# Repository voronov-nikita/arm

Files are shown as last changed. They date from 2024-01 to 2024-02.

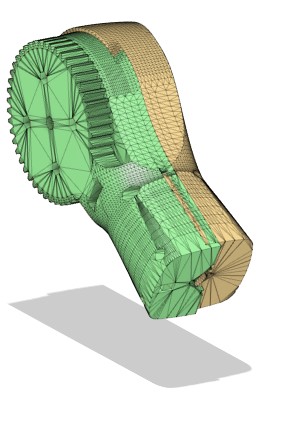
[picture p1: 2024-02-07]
scheme/5.jpg

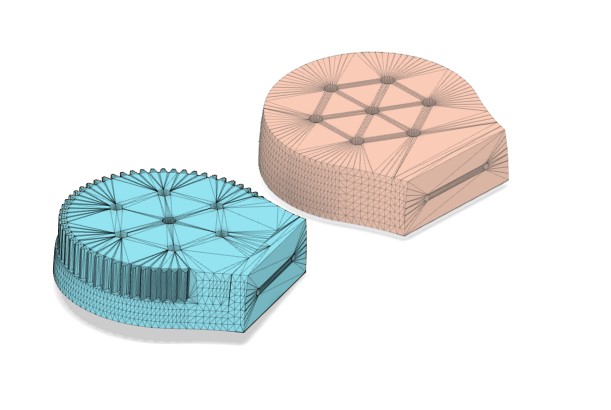
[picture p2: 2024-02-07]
scheme/4.jpg

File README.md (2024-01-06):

# ARM

<div align="center">
  Изображение
</div>

Проект - робот манипулятор на базе Arduino с особым управлением.

<br><br>

## Содержание

1. [О проекте](/README.md#о-проекте)
2. [О проекте](/README.md#используемые-компоненты)
3. [Структура проекта](/README.md#структура-проекта)
4. [Лицензии проекта](/README.md#лицензии)
5. [Полезные ссылки](/README.md#полезные-ссылки)

## О проекте

## Используемые компоненты

1. фывы
2. цацс
3. ывс
4. ысыв

## Структура проекта

## Лицензии

Проект распространяется с открытым исходным кодом под лицензией [MIT](/LICENSE).

## Полезные ссылки

1. [arduino.cc](https://www.arduino.cc)
2. [amperka.ru](https://amperka.ru/)

<br><br>

###### 06.01.2024

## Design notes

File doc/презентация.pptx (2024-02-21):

## Робот манипулятор

Государственное бюджетное общеобразовательное учреждение города Москвы «Школа № 1532»

11 класс, ГБОУ школа № 1532,
Воронов Никита Рустамович 11 «А»
Руководитель:
учитель информатики, ГБОУ школа №1532,
Кузьмин Михаил Игоревич

## Идея проекта

Создании универсальной и гибкой мехатронной системы, обеспечивающей автоматизированное выполнение разнообразных задач с высокой точностью и эффективностью.

## Принципы манипулятора 1 3 4 2

Механика

- Физическая структура манипулятора
- Кинематика и динамика движений

Восприятие

- Система сенсоров робота
- Обработка данных сенсоров для расчета положения

Управление

- Алгоритмы управления для точного перемещения
- Система обратной связи для коррекции движений

Взаимодействие

- Интеграция манипулятора с другими системами
- Возможность взаимодействия с внешней средой

## Этапы реализации

Подготовка материалов

- Создание 3Д моделей
- Выбор компонентов

Реализация материалов

- Печать готовых моделей
- Сборка устройств

Программирование

- Разработка специального скетча и прошивка обоих устройств

Тестирование

- Тестирование готового оборудования

## Распределение времени

Моделирование

Печать моделей на 3Д принтере

Программирование устройств

Тестирование

20%

50%

25%

5%

## Где можно применить?

## Способы применения

- Опасные для жизни места
- Труднодоступные места
- Технические производства
Все зависит от пользователя!

## Схема подключения перчатки

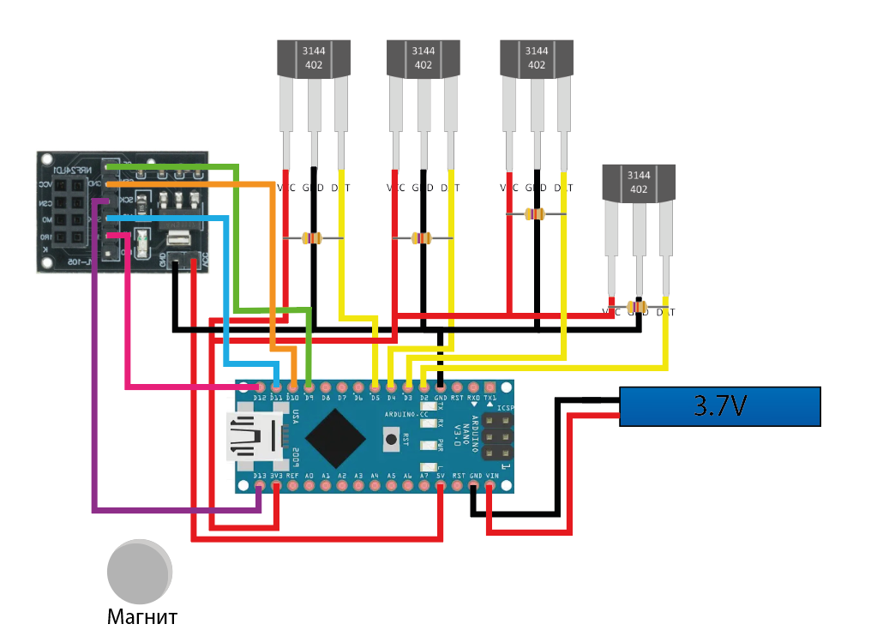
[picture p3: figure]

## Манипулятор

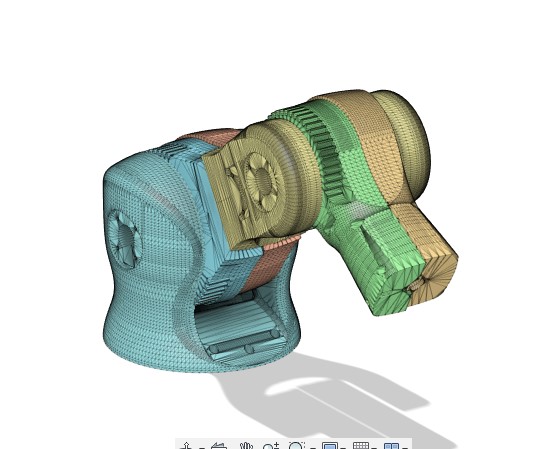
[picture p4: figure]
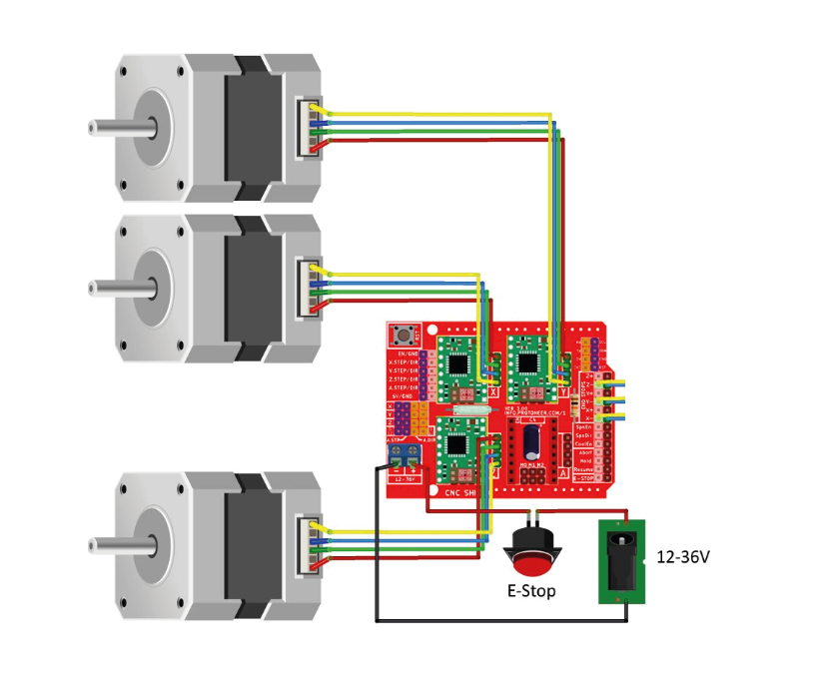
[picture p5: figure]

## Открытый исходный код

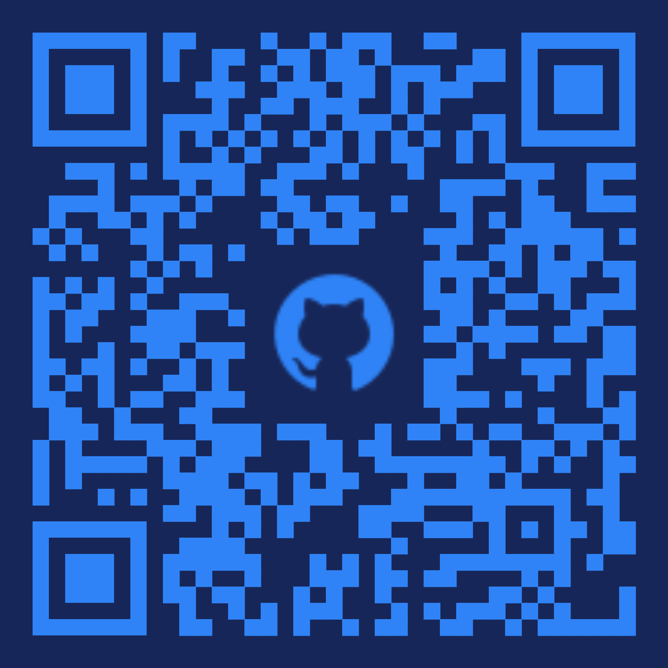
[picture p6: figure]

A

Код манипулятора

Исходный код манипулятора в виде arduino скетча

C

Модели

Исходные модели 3Д печати

B

Код перчатки

Исходный код перчатки в виде arduino скетча

D

Лицензия

Проект распространяется под лицензией MIT

## Спасибо

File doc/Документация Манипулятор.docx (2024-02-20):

Государственное бюджетное общеобразовательное учреждение города Москвы «Школа № 1532»

Разработка робота-манипулятора с копирующим управлением на основе жестов руки человека

11 класс, ГБОУ школа № 1532,

Воронов Никита Рустамович 11 «А»

Руководитель:

учитель информатики, ГБОУ школа №1532,

Кузьмин Михаил Игоревич

Москва, 2024

# Содержание

1. Поисково-исследовательский этап 3

1.1. Актуальность проекта 3

1.2 Цели и задачи 3

1.3 Анализ аналогов 4

1.4 Функциональная схема и формулировка технического задания 6

2. КОНСТРУКТОРСКО-ТЕХНОЛОГИЧЕСКИЙ ЭТАП 8

2.1 Выбор технического оборудования 8

2.2 Конструкционные особенности 9

3. Результаты 12

4. Приложение 13

4.1 Программный код 13

4. Список используемых ресурсов 13

# 1. Поисково-исследовательский этап

## 1.1. Актуальность проекта

На данный момент в мире активно развивается автоматизация производств и логистики с использованием различных видов роботов. Роботы-манипуляторы, управляемые инновационными методами, становятся важным направлением в робототехнике. Этот проект фокусируется на создании прототипа робота-манипулятора с управлением через контроллер-перчатку. Этот подход не только обеспечивает эффективное взаимодействие человека с роботом, но и решает проблемы эргономики и удобства управления.

Такой робот может быть применен в различных сферах, таких как медицина, строительство, промышленное производство, а также в ситуациях, где важны точность и чувствительность воздействия. Контроллер-перчатка делает управление роботом более естественным и интуитивным, уменьшая необходимость специализированного обучения пилотов устройства.

Проект также решает задачи, связанные с эргономикой и удобством управления. Это делает робота-манипулятора более доступным и простым в использовании, что может повысить эффективность в различных областях. Робот с контроллером-перчаткой особенно ценен в условиях, где требуется высокая точность и тонкость взаимодействия с объектами, в том числе в зонах, где человеку находиться даже короткий промежуток времени опасно.

Поэтому разработка технологически передового робота-манипулятора и инновационного метода управления, способствует улучшению взаимодействия человека с техникой в различных областях применения.

## 1.2 Цели и задачи

Цель работы: разработать полноценную модель робота манипулятора с управлением через специальный контроллер-перчатку.

Для успешного и эффективного выполнения цели проекта необходимо решить ряд следующих задач работы:

1. Проанализировать аналоги и готовые прототипы;

Провести исследование рынка и технологических решений для выявления существующих аналогов и прототипов, определить их преимущества и недостатки.

2. Составить функциональную схему продукта;

Определить основные функциональные элементы и взаимосвязи между ними, создавая понятную схему для последующего проектирования.

3. Составить электрическую схему модели;

Разработать детальную электрическую схему, описывающую подключение и взаимодействие электронных компонентов робота.

4. Разработать трехмерную модель конструкции в программе 3D моделирования;
5. Подобрать необходимые компоненты и материалы;
6. Разработать печатные/макетные платы для размещения электроники;

Создать дизайн печатных плат, обеспечивающих эффективное размещение и взаимодействие электронных элементов.

7. Изготовить/Подготовить материалы для реализации модели робота;
8. Собрать конструкцию робота и объединить все компоненты;

Выполнить сборку робота, установить компоненты согласно проектной документации, обеспечивая их взаимодействие.

9. Разработать программу для манипулятора и перчатки;
10. Запрограммировать перчатку и манипулятор;
11. Протестировать и модифицировать конструкцию и электронику робота;
12. Оценить и представить выполненную работу.

## 1.3 Анализ аналогов

В процессе исследования были рассмотрены аналоги и прототипы, представленные другими известными производителями роботов или командами энтузиастов. Подробная информация о сравнительных характеристиках этих манипуляторов приведена в таблице 1. В таблице представлена детализированная информация о ключевых особенностях и параметрах этих манипуляторов, призванных воплощать в себе передовые технологии и инженерное мастерство.

Таблица 1. Анализ аналогов роботов-манипуляторов, представленных на рынке.

Название | Визуальная картинка | Характеристики

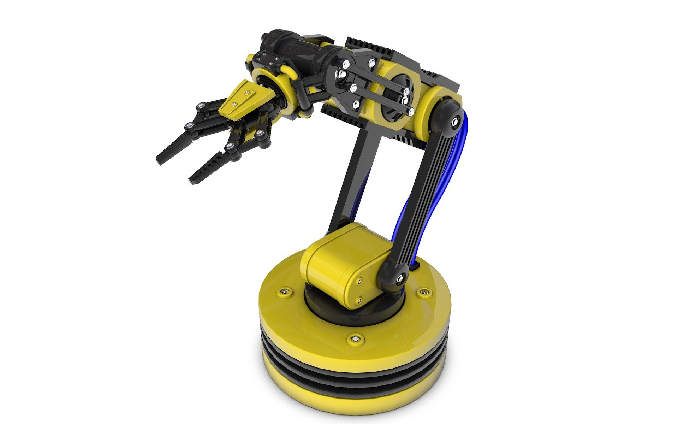
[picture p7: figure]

Робот-манипулятор LD-tg1400-6 | | Полезная нагрузка манипулятора достигает 6 кг. Рабочий радиус взаимодействия в районе 1000 мм Конструкция описана в виде Шарнирно-сочлененной структуре. Число степеней свободы - 4. Повторяемость: ±0.05 мм. Вес около 60 кг. Рабочая температура находиться в диапазоне -20°C~80°C

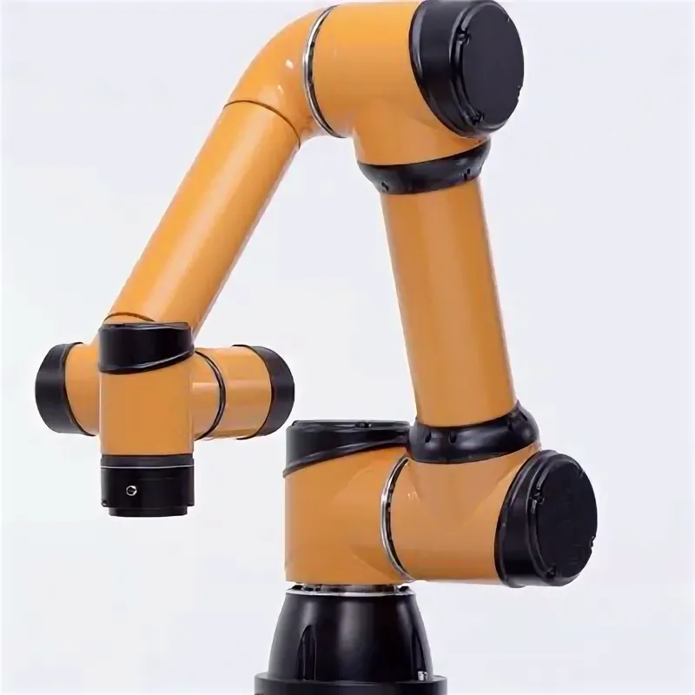
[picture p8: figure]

Манипулятор AUBO i5 | | Манипулятор AUBO i5 предполагает полезную нагрузку до 6 кг и рабочий радиус в 1000 мм. В его конструкции присутствует 6 степеней свободы, обеспечивая высокую гибкость. Повторяемость в пределах ±0.1 мм, вес составляет примерно 40 кг. Способен эффективно функционировать в широком температурном диапазоне от 10°C до 50°C

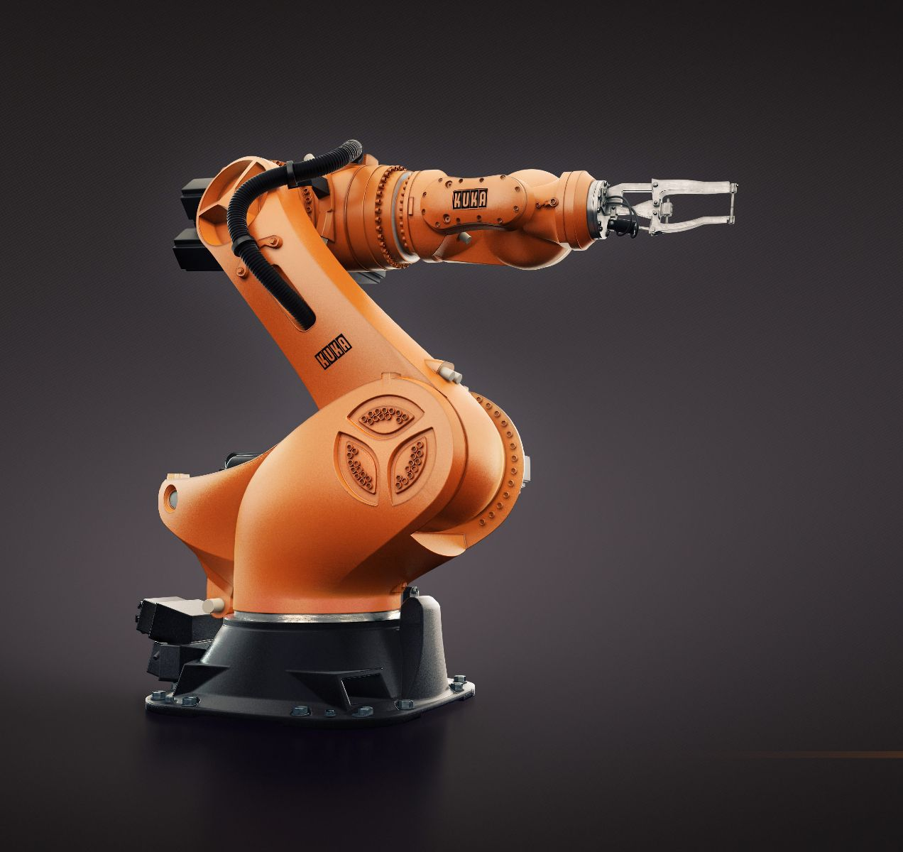
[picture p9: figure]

Робот-манипулятор Kuka KR AGILUS | | Полезная нагрузка: от 3 до 10 кг. Рабочий радиус - от 600 до 1100 мм. Основная структура робота: Шарнирно-сочлененная конструкция с 6 степенями свободы. Повторяемость: высокая точность с повторяемостью в пределах ±0.02 мм. Вес в диапазоне 51-70 кг. Рабочая температура: стандартно в диапазоне от 10°C до 55°C.

Все эти манипуляторы имеют идентичную структурную особенность - последовательную кинематику, однако их параметры значительно отличаются друг от друга.

## 1.4 Функциональная схема и формулировка технического задания

Основной функциональной особенностью данного манипулятора является возможность управления им с использованием специальной перчатки, оборудованной сенсорами и датчиками. Эти устройства на перчатке реагируют на движения рук и пальцев пользователя, а затем транслируют эти данные в манипулятор для выполнения соответствующих задач. Для тех, кому вариант с управлением через перчатку не подходит, можно использовать другой контроллер, напоминающий обычный джойстик со стандартным управлением.

Перчатка обеспечивает точное и мгновенное распознавание жестов и движений, что позволяет оператору контролировать манипулятор с высокой степенью прецизионности. Такое управление особенно полезно в задачах, где требуется тонкая настройка и точность, например, в хирургии, производстве микроэлектроники или при работе с труднодоступными объектами.

Кроме того, система может быть дополнена силомоментной обратной связью, позволяющей пользователю чувствовать вес, форму и текстуру объектов, с которыми взаимодействует манипулятор. Это создает ощущение присутствия и повышает уровень контроля оператора.

Такой манипулятор с копирующим управлением представляет собой интегрированную и эргономичную систему, которая может быть применена в различных областях, требующих высокой точности и удобства управления.

В итоге было сформулировано следующее техническое задания:

1. Необходимо обеспечить стабильную связь между роботом манипулятором и контроллером удаленного управления. Перчатка или иной контроллер требуют постоянного питания, так как канал связи должен быть постоянно занят. Реализовать постоянную обратную связь между манипулятором и контроллером не сложно, однако хочется, чтобы при работе от аккумулятора перчатка или контроллер не разряжались в один момент, даже если данных не поступало.
2. Необходимо реализовать алгоритмы калибровки шаговых двигателей. Вся проблема в том, что при использовании шаговых двигателей в момент запуска, в большинстве случаев, они берут за свою стандартную позицию ту, с которой запустилась, а не ту, которую подразумевается. Для исправления этого недочета есть несколько способов решения, одним из них является способ калибровки манипулятора с помощью специальных алгоритмов.
3. Реализовать схему считывания данных от пользователя и перевод их на манипулятор. Для этого необходимо использовать модель радиосвязи NRF. Данные с перчатки передаются на манипулятор по специальному радиоканалу, настроенного вручную.
4. Реализовать модель перчатки. В перчатке должен присутствовать микроконтроллер на базе Arduino. Данные об отклонении руки на заданном промежутке считываются с помощью датчика гироскопа-акселерометра mpu6050. В схеме должны присутствовать датчики магнитного поля или датчики холла. Закрепить датчики следует на 4-х пальцах перчатки, а на большом пальце той же перчатки необходимо разместить небольшой магнит.
5. Разработать алгоритм перевода угла наклона в скорость вращения определенного шагового двигателя. Для перевода угла наклона в скорость, вам необходимо учитывать изменение угла по времени. В физике и математике угловая скорость (или скорость вращения) обозначается символом ω (омега) и измеряется в радианах в секунду (рад/с).
6. Составить схему для манипулятора и реализовать ее в реальной жизни. Схема и 3Д модель должны соответствовать требованиям документации и правилам, описанным ГОСТ.
7. Разработать прошивку для перчатки и робота-манипулятора. Для реализации следует использовать микроконтроллер Arduino и среду программирования Arduino IDE. Необходимо, чтобы перчатка имела у себя 4 отдельных датчика холла на каждом пальце, за исключением большого пальца руки.
8. Протестировать систему в реальных условиях. Попробовать поднять предметы разной формы и веса в пределах допустимой нагрузки. В зависимости от проведенных тестов сделать техническую документацию, описывающие характеристики манипулятора.
9. Составить полную документацию к проекту.

# 2. Конструкторско-технологический этап

## 2.1 Выбор технического оборудования

Для проектирования моделей использовался Autodesk Fusion 360. Он является мощным программным обеспечением для компьютерного-помощи-в-проектировании (САПР), предоставляющим ряд преимуществ, объясняющих его широкую популярность. Интегрированный подход Fusion 360 предоставляет интегрированную среду для 3D-моделирования, инженерного проектирования, симуляции, CAM (компьютерно-чертежное проектирование) и облачного хранения. Это позволяет пользователям работать над всеми аспектами проекта в одной среде, что способствует синхронизации данных и упрощает взаимодействие между различными этапами проектирования. Широкий функционал Fusion 360 включает в себя множество инструментов для создания 3D-моделей, выполнения анализа напряжений и тепловых карт, создания инструментальных траекторий для станков с ЧПУ и многое другое.

Для программирования основного микроконтроллера ATmega2560 было решено использовать среду Arduino IDE с оболочкой под ATmega2560 и язык программирования C++. Этот микроконтроллер является основой Arduino Mega, что обеспечивает широкие возможности для разработки и управления различными периферийными устройствами. Необходимый чип как раз используется платой Arduino Mega, именно она в проекте и была взята.

## 2.2 Конструкционные особенности

Для дальнейшей работы определим необходимые компоненты копирующего управления. Начнем непосредственную разработку с выполнения схемы перчатки. В качестве датчиков, управляющих движениями робота-манипулятора было принято решение использовать датчик гироскоп-акселерометра mpu6050. В зависимости от угла отклонения и вычислительного ускорения формируется понятие того, куда, как и с какой скоростью должен вращаться определенный двигатель. Для обеспечения взаимодействия пользователя и манипулятора, а также для интерпретации показаний датчиков использована плата Arduino Nano. Связь между элементами осуществляется по радиоканалу, который обеспечивают модули NRF24, установленные как на перчатку, так и на сам манипулятор. В качестве питающего элемента использован аккумулятор типа 18650 на 3.7 В. Данного аккумулятора хватит для использования перчатки в автономном режиме без дополнительных модулей усиления. Таким образом схема сборки электронных компонентов приведена на рисунке 1.


Рисунок 1. Схема сборки устройства, считывающего жесты, закрепленного на перчатке.

Далее перейдем к разработке манипулятора. Для первого прототипа будем использовать шаговые двигатели типа NEMA17. Такие двигатели широко распространены на рынке и обеспечивают необходимую точность перемещений робота, однако они имеют небольшой момент силы. Чтобы нивелировать этот недостаток, в манипуляторе применяются зубчатые передачи, установленные на звеньях. Модель манипулятора, построенного в программе Fusion 360 приведена на рисунке 2.


Рисунок 2. Манипулятор, построенный в программе Fusion 360.

Производство будет выполнено на 3D-принтере Flying Bear 5, что обеспечит необходимое качество производимых деталей. На рисунке отмечено цветами разделение частей деталей для производства. Далее перейдем к формированию электронной схемы компонентов манипулятора.

Как было описано выше, для обеспечения перемещений роботом будут использованы двигатели типа NEMA17,которые будут подключены к плате Arduino с помощью драйвера A4988. Данный драйвер не требователен к управляющему сигналу, что делает его наиболее эффективным в этом проекте. Данные для перемещения Arduino будет получать с помощью радиомодуля NRF24. Сигнал можно усилить, поставив на место обычной NRF24 ту же модель, но с модулем усиления и антенной. Электросхема манипулятора приведена на рисунке 3.


Рисунок 3. Электросхема управления манипулятором.

Таким образом схема управления манипулятором составлена. Теперь необходимо обеспечить сборку и взаимодействие оператора с манипулятором. Для этого составлена программа на языке Arduino, приведенная в приложении.

# 3. Написание программного кода проекта

## 3.1 Программный код перчатки

Программный код перчатки реализован на языке программирования C++. Используемые библиотеки находящиеся в открытом доступе. На рисунке 4 представлен фрагмент кода, на котором происходит момент инициализации перчатки, открытие радиоканала и инициализация самой mpu6050. Уникальный адрес для радиоканала задается вручную, что может показаться не совсем эффективным, но надежным и постоянным. Это делает перчатку менее зависимой от конкретного разработчика или администратора.

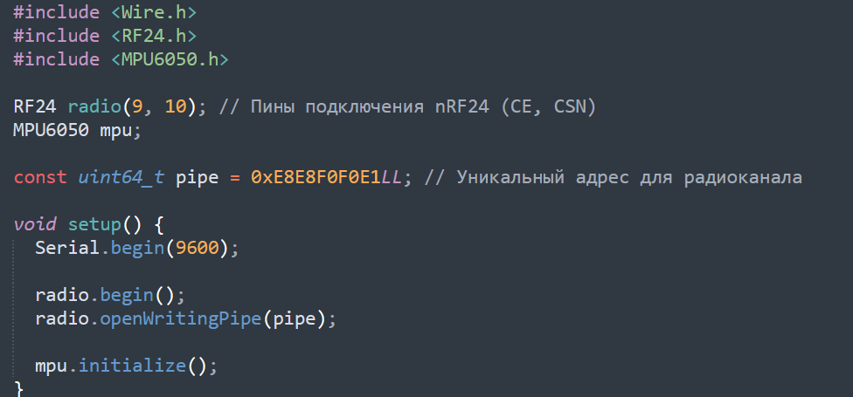
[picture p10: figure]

Рисунок 4. Пример программного кода для инициализации перчатки.

## 3.2 Написание программного кода манипулятора.

На рисунке 5 представлен код обработки полученных данных на стороне манипулятора.

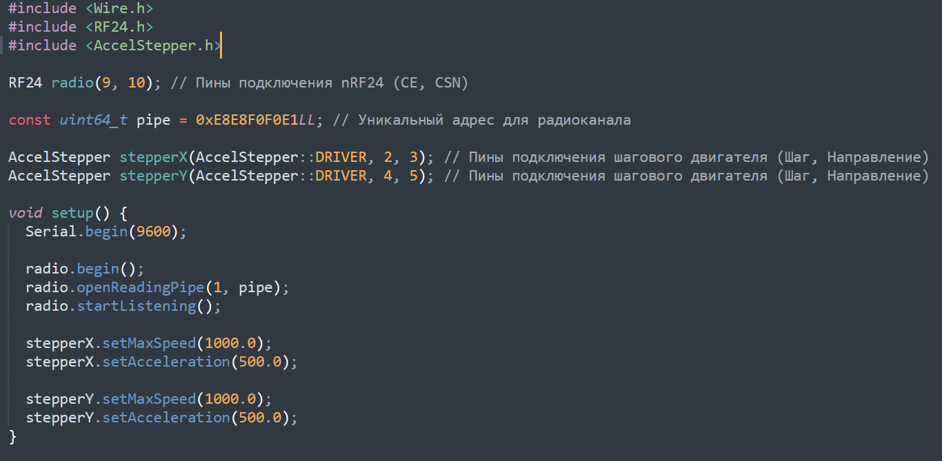
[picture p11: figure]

Рисунок 5. Пример обработки данных от перчатки.

Важно понимать, что номера радиоканалов должны совпадать друг с другом, иначе соединения двух модулей между собой не произойдет.

# 4. Результаты

Цели и задачи данного проекта выполнены в полном объеме. Разработана вся необходимая документация, построены модели и электросхемы, детали переданы в производство, где успешно выполнены. Произведена дополнительная механическая обработка деталей из-за некоторых незначительных дефектов производства. Схемы собраны и дополнительно скорректированы для документации. Написан программный код, и обеспечивается устойчивое соединение между оператором и манипулятором. Проект проходит стадии финальной отладки и оптимизации.

# 5. Список используемой литературы

1. Банци М.« Arduino для начинающих волшебников»

https://www.elec.ru/library/nauchnaya-i-tehnicheskaya-literatura/banci-arduino/ Дата обращения: 25.12.2023;

2. Олег Миловзоров, Иван Панков - «Электроника. Базовый курс»

https://krasnograd2008.ucoz.ru/load/uchebniki_dlja_vuzov/uchebniki_dlja_vuzov/oleg_milovzorov_ivan_pankov_ehlektronika_bazovyj_kurs/60-1-0-1887 Дата обращения: 16.01.2024;

3. «Основы 3д моделирования в Компас 3Д» https://youtube.com/playlist?list=PLivkchQQojUVkmjov0UZrLz2X70HkV4gK&si=_3Ym10-ELJgqKk2p Дата обращения: 3.02.2024;
4. Пол Шерц и Симон Монк «Практическая электроника для изобретателей»

https://zametkioknigah.blogspot.com/2015/02/practical-electronics-for-inventors.html Дата обращения: 8.01.2024;

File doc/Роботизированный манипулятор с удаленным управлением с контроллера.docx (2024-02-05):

Роботизированный манипулятор с удаленным управлением с контроллера

Работа ученика школы №1532:

Воронова Никиты Рустамовича

Руководитель проекта:

Кузьмин Михаил Игоревич

Введение

В основе разработки роботизированных устройств всегда лежит один принцип – облегчить какую-то рутинную задачу. Ярким примером этого принципа являются умные пылесосы. Они созданы с целью автоматизации и упрощения процесса уборки в доме. Эти роботы способны самостоятельно перемещаться по помещению, обнаруживать загрязнения и эффективно очищать поверхности. Такие устройства значительно снижают необходимость ручной уборки, освобождая время для более важных и интересных занятий.

Но мой проект не о роботе пылесосе. Есть вещи, которые людям сложно выполнять в каких-то местах. Обычно для таких целей создают роботов, которые могли бы в этом помочь. Роботизированный манипулятор – это один из таких роботов.

Суть манипулятора в том, чтобы в зависимости от общего положения всех своих двигателей выдавать определенную форму или позу, из которой в последствии можно выбрать необходимые действия.

О проекте

Проект разработан с целью обеспечить безопасное взаимодействие человека с разными объектами и в разных опасных ситуациях. Людям постоянно приходиться работать в сложных и опасных для жизни местах. Робот-манипулятор способен справиться с этой проблемой, предоставляя уникальные возможности для выполнения различных задач в опасных средах. Например, в ядерных электростанциях, где существует потенциальная угроза радиации, робот-манипулятор может осуществлять рутинные проверки, обслуживание и даже ремонт оборудования без участия человека.

В случае чрезвычайных ситуаций, таких как природные катастрофы или аварии на промышленных объектах, робот-манипулятор может быстро развернуться для поиска и спасения, а также для предотвращения дополнительных угроз. Его способность работать в сложных территориальных условиях и выполнять множество задач позволяет оптимизировать эффективность оперативных мероприятий.

В промышленности роботы-манипуляторы обеспечивают безопасность работников при обработке опасных материалов и в труднодоступных местах, где могут быть высокие температуры, ядовитые вещества или другие опасности. Это повышает производительность и снижает риск профессиональных заболеваний.

Также в медицинской сфере робот-манипулятор становится незаменимым помощником в хирургии, позволяя врачам проводить сложные операции с высокой точностью, минимизируя риски для пациента.

Манипулятор по своему строению похож на человеческую руку, с некоторыми модификациями. Подобно тому, как человек управляет своей рукой можно добиться того, как человек управляет роботом.

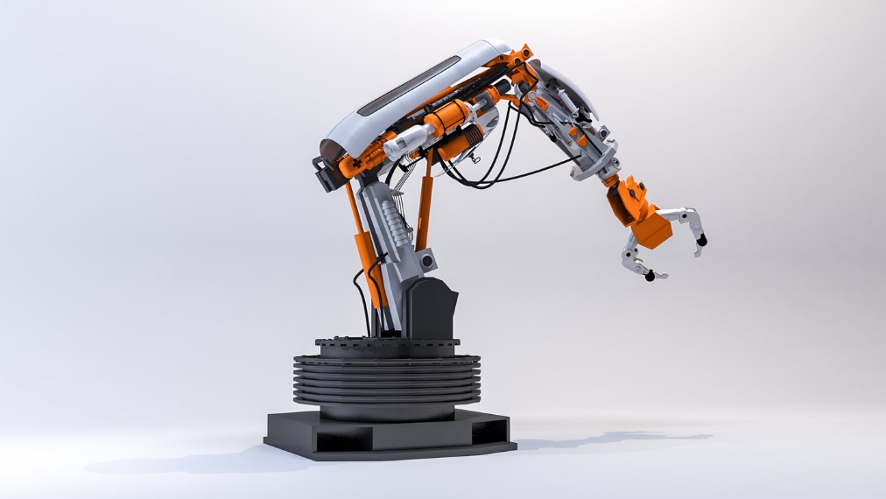
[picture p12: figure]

Рис.1 Пример робота-манипулятора

Вся система состоит из двух частей: роботизированный манипулятор и удалённый контроллер управления. Обмен данными происходит по радиоканалу с использованием модулей NRF24L01. Канал достаточно настроить один раз на обоих устройствах. Конечно, куда проще было бы настроить автоматический поиск свободных радиоканалов, но в таком случае есть рис попасть в чужой радиоканал, который находился в режиме ожидания. Таким образом возрастают риски того, что управление манипулятором может быть опасным или бессмысленным.

В основе идеи лежит сделать подобие роботизированного помощника, подобно тому, которого нам показали в фильме «Железный человек»

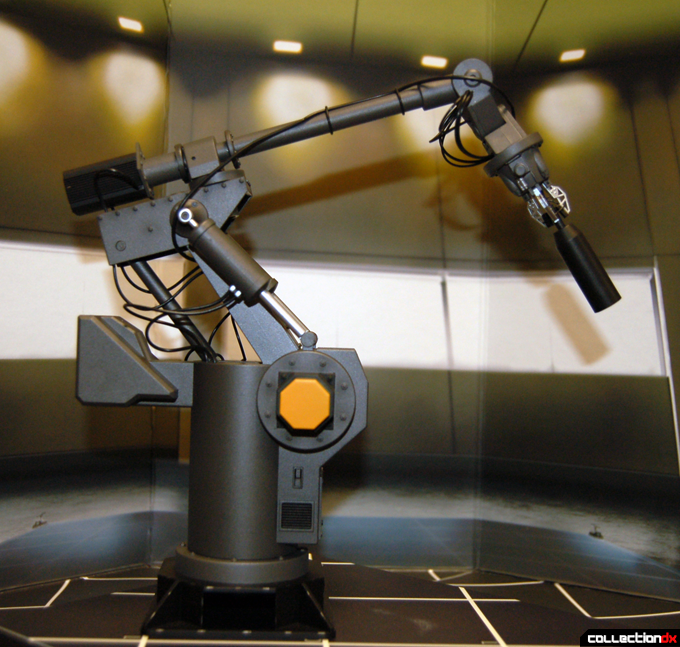
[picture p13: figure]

Рис.2 Пример манипулятора из фильма

Разумеется, что повторить все функции робота из фильма не получиться, но сама идея вполне реализуема.

Подробнее с файлами работы, готовым кодом и примерами использования можно ознакомиться по ссылке на репозиторий GitHub:

https://github.com/voronov-nikita/arm

Принцип работы

Как уже было сказано ранее, вся система состоит из ручного контроллера – перчатки и самого роботизированного манипулятора. Обе части работают на базе микроконтроллеров Arduino с различными усилителями. Рассмотрим принцип работы каждого из них по отдельности.

Перчатка – это специальный контроллер, который собирает данные о положении руки человека и отправляет соответствующие данные по радиоканалу. Данные, которыми обмениваются контроллер и манипулятор – это 3 угла отклонения (roll, pitch, throttle), 4 показателя от датчиков холла, положение перчатки по вертикальной оси и положение перчатки по оси вращения yaw. NRF модули свободно способны обмениваться большими данными в формате массивов. Таком образом для массива достаточно использовать только целые числа, не выходящие за пределы 16 битного представления числа. Следовательно, по формуле поиска общего объёма информации:

I=k*i

Можно получить такие параметры, где k – это количество информации, а i – размер каждого элемента этой информации. В нашем случае k – это размер массива, а i – это размер целых чисел в языке программирования C++, соответственно от 16 до 128 бит информации. Как раз размер массива умещает в себя 9 значений, необходимых для изменения движения манипулятора. А размер каждого должен умещаться в 16-битную разрядность двоичной системы счисления. Соответственно общий объем информации это 16бит * 9 = 144 бита. Скорость передачи данных у NRF24L01 в районе 0,25Мбайт/секунду. Переводя в обратные единицы, получим, что наш пакет данных дойдет и вернется за ~0,41 секунд. Разумеется, что это скорость при идеальных условиях, а в нашем мире легко получить помехи в соединении. Поэтому, с условиями погрешности, была взята скорость в диапазоне от 0 до 1 секунды. Этого всего уже достаточно, чтобы обеспечить практически бесперебойную связь на расстоянии до 2-х километров.

Для получения положения руки управляющего используется модуль гироскоп-акселерометра MPU6050 с Arduino совместимым стабилизатором.

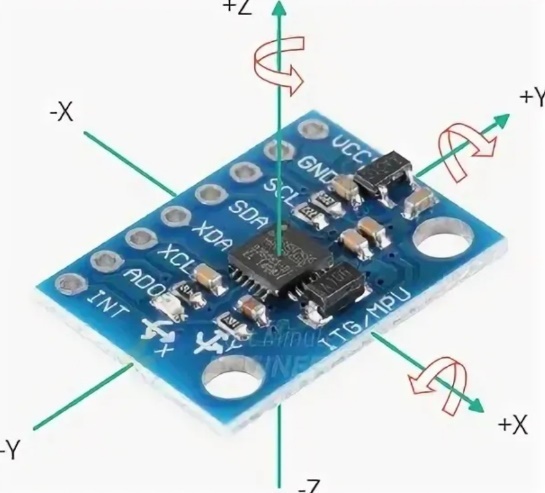
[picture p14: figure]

Для симметричных тел, вращающихся вокруг главной оси, момент импульса (L) равен произведению момента инерции тела (I0) на его угловую скорость вращения (ω0). Это выражается уравнением:

Рис.3 mpu6050

L=I_0 *w_0

Момент инерции (I) зависит от массы и распределения массы относительно оси вращения. Вектор момента импульса (L) определяет точность работы гироскопических приборов: чем он больше, тем устойчивее и точнее функционируют эти приборы. Но при таком раскладе мало просто использовать некоторые значения, вычисляемые из этой формулы, нам необходимо сделать что-то вроде преобразователя. Используя данные гироскопа для оценки угла, легко можно найти угол отклонения (θ), интегрируя угловую скорость (ω):

θ(t)=θ_0 +∫_(t_0)^t ω( ʇ)Δ ʇ

Однако, данная формула подвержена ошибкам из-за дрейфа гироскопа, и поэтому для более точных результатов часто применяют фильтры, такие как фильтр Калмана, для коррекции данных.

Фильтр Кальмана начинает с предсказания текущего состояния системы, основываясь на предыдущих измерениях и знании о том, как система обычно изменяется. Например, если мы измеряем угловую скорость (как быстро что-то вращается), мы можем предсказать, на сколько изменится угол поворота за следующий короткий период времени. Затем фильтр Кальмана принимает новое измерение текущего состояния системы. Но измерения часто содержат шумы или ошибки. Фильтр сравнивает предсказание с фактическим измерением и определяет, насколько они различаются. Затем фильтр учитывает, насколько ему можно доверять предсказанию и насколько измерение подвержено шумам. На основе этих сравнений фильтр корректирует предсказание, чтобы получить более точное состояние системы. Важно отметить, что фильтр Кальмана учитывает как измерения, так и динамические свойства системы. Он стремится минимизировать ошибки оценки состояния, учитывая неопределенность в данных и модели системы. Это позволяет ему быть эффективным инструментом для оценки состояния в реальном времени в различных областях, таких как навигация, управление роботами и другие приложения.

Для отслеживания режимов работы и изменении каких-то прочих параметров используются цифровые датчики холла, расположенные в районе 4-х пальцев. Всего из 4-х датчиков формируются специальные команды для перчатки. Для активации датчика необходимо поднести выбранный датчик к большому пальцу руки, именно там располагается магнит для активации датчика. К примеру, если замкнуть перчатку на указательный и большой палец, то данные для манипулятора перестанут передаваться, манипулятор застынет на одном месте, а человек сможет передохнуть. Если замкнуть средний и большой пальцы, то можно вызвать команду закрытия или открытия руки манипулятора. Это должно облегчить понимание структуры и процедуры открытия и закрытия манипулятора. Если же замкнуть безымянный и большой палец, то можно подать команду манипулятору «Вернуться в начальное положение». Это облегчит процесс выключения робота и подготовку к транспортировке. Если замкнуть большой палец и мизинец, то можно вызвать работу, заранее записанного алгоритма действий. Это делает манипулятор более автономным и независимым от пилота. При повторном замыкании автоматический алгоритм просто приостановит работу.

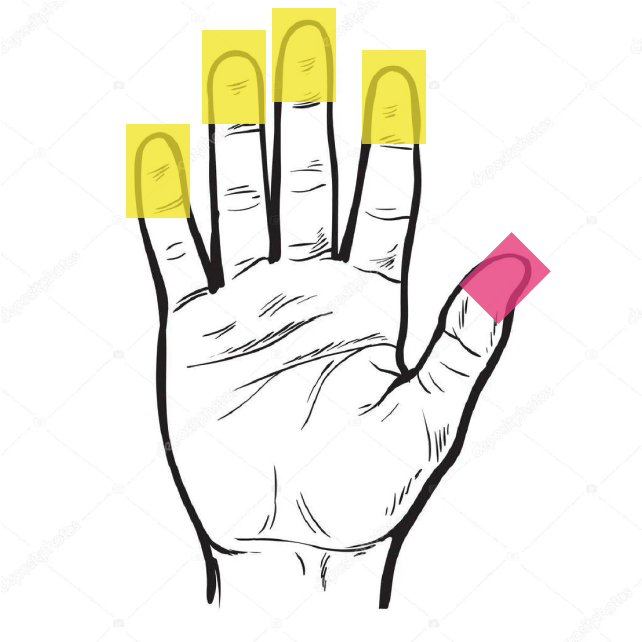
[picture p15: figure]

Рис.4 Абстрактное представление расположение датчиков и магнита в перчатке

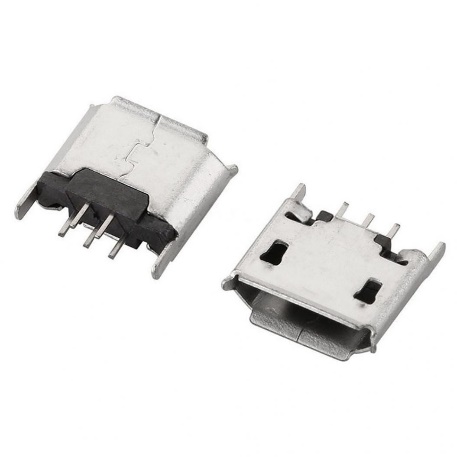
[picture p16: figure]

Схема перчатки довольна простая, но со своими особенностями. Так как устройство должно быть автономным, необходимо предусмотреть возможность питать микроконтроллер от аккумулятора. Но важно помнить, что и аккумулятор нужно периодически заряжать. Для этого момента был взят специальный разъем для одновременной зарядки аккумулятора и питании микроконтроллера Arduino. Таким образом заржать перчатку можно от обычной зарядки для телефона. Перчатка способна работать от аккумулятора без перерыва на протяжении около 6 часов. Все дело в том, что сама Arduino требует не так много питания и несмотря на то, что у нее присутствуют тяжелые 5V датчики, требующие постоянного питания, это не мешает перчатке работать в экономном режиме. Это делает конструкцию меньше и проще в разработке, однако это усложняет логические цепочки при программировании контроллера.

Рис. 5 Разъем питания microusb

В создании самого манипулятора гораздо больше мелких деталей, про которые важно помнить, уметь применять и исследовать зависимости и закономерности. К примеру, приходиться постоянно вычислять новые параметры для угла отклонения каждой отдельной части манипулятора. В самой конструкции манипулятора полно компонентов, требующих постоянную работу с относительно высоким напряжением (от 12V до 35V). Одним из таких компонентов является шаговый двигатель Nema17.

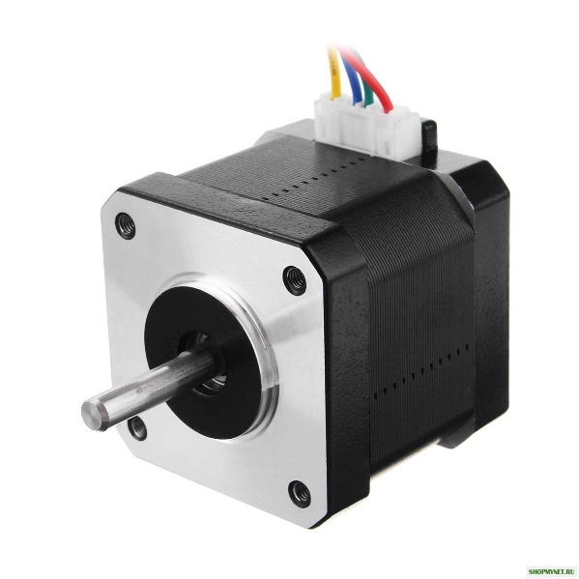
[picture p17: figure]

Nema 17 – это шаговый двигатель, который часто используется в системах управления роботами, манипуляторами, 3Д принтерах, ЧПУ станках и д.р. Благодаря своим характеристикам.

Рис. 6 Внешний вид двигателя Nema17

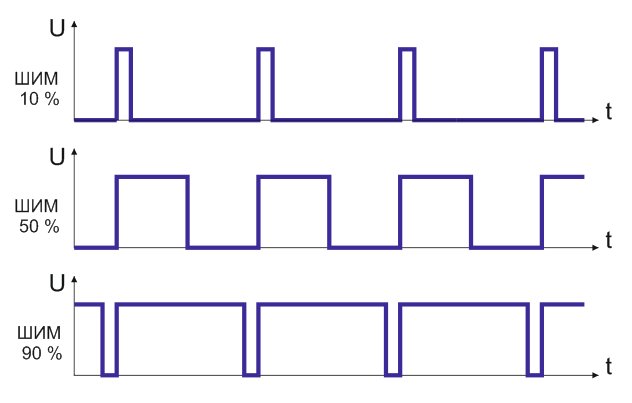
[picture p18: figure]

Шаговый двигатель Nema 17 обладает довольно высокой точностью. Они предоставляют высокую точность позиционирования, что важно для точного управления манипулятором. Так же ими довольно легко управлять. Разные модели двигателя Nema 17 представляют разные размеры, но те, что использовались при создании манипулятора обладают относительно малыми размерами. Стоит сказать, что изначально планировалось использовать коллекторные или бесколлекторный двигатель. Однако после более тщательного изучения характеристик было принято решение заменить их на шаговые. Все дело в том, что бесколлекторный двигатели используют достаточную модель вращения, однако отследить количество вращений без дополнительных устройств не получиться. Была идея использовать систему с магнитами, но скорость этих двигателей не позволяет точно отследить каждый оборот. В случае с коллекторными двигателями все еще хуже. Так как они не используют дополнительный сигнальный контакт для управления скоростью приходилось использовать ШИМ сигнал для регулирования оборотов.

Рис. 7 Пример вывода ШИМ сигнала с разными частотами

Используя широтно-импульсную модуляцию, мы сталкиваемся со множеством проблем. К примеру, она могут создавать электромагнитные помехи, что может вызывать внешние воздействия на соседние системы и приводить к появлению шумов в сигнале. Применение ШИМ может потреблять больше энергии по сравнению с аналоговыми методами управления, так как в процессе модуляции генерируется высокочастотный сигнал, что требует дополнительной энергии. Использование ШИМ требует высокой стабильности и точности в управляющих схемах. Отклонения могут привести к неправильной модуляции, что в свою очередь может вызвать искажение сигнала.

Для управления шаговыми двигателями необходимо использовать отдельные сигналы на обмотки для создания шагового движения. Это обеспечивает точное управление позиционированием и обеспечивает возможность простой реализации движения манипулятора в заданных угловых координатах. Таким же образом можно отслеживать количество пройденных оборотов двигателя для подсчета новой позиции. Это может в дальнейшем помочь при выставлении начальной позиции и сохранении позиций в энергонезависимой памяти устройства.

Для управления лучше всего использовать микроконтроллер Arduino. Использование Arduino в проекте манипулятора обеспечивает простоту в разработке и программировании. Arduino предоставляет удобный программный интерфейс, что делает процесс создания и управления манипулятором более доступным и гибким.

Разумеется, что просто так управлять подобным устройством не получиться. Необходимые контролеры для шаговых двигателей используют большое напряжения, а в этой конструкции еще и к каждому приходиться подводить собственное питание, чтобы не получить какие-нибудь сетевые ошибки. Поэтому использование специальной платы расширения выглядит не очень плохой идеей.

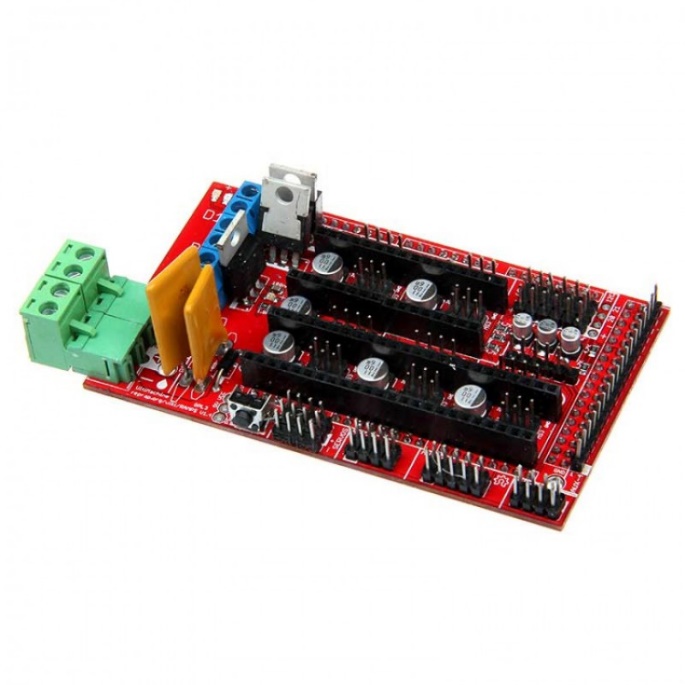
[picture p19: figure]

Рис. 8 Плата расширения для управления шаговыми двигателями

Схема обмена данными в манипуляторе схожа с той, что представлена в перчатке. Однако здесь важно понимать, что в отличие от перчатки, манипулятор должен принимать сигнал и обрабатывать его на своей стороне. Здесь используется тот же радио модуль обмена данными NRF24L01. Канал передачи данных используется тот же, что и на перчатке. Только в таком случае получиться стабильно обмениваться данными на больших расстояниях, вплоть до 2-х километров без усилителя.

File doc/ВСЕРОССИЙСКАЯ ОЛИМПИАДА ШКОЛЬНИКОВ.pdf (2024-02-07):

ВСЕРОССИЙСКАЯ ОЛИМПИАДА ШКОЛЬНИКОВ

Технология. Профиль
«Робототехника»

### Проект

### Разработка робота-манипулятора с копирующим управлением на основе жестов руки человека

Работу выполнял:

Воронов Никита Рустамович

Руководитель:

Кузьмин Михаил Игоревич

### Содержание

1.4 Функциональная схема и формулировка технического задания.........6

### 1. Поисково-исследовательский этап

### 1.1. Актуальность проекта

На данный момент в мире активно развивается автоматизация производств и логистики с использованием различных видов роботов.
Роботы-манипуляторы, | управляемые | инновационными | методами,
становятся важным направлением в робототехнике. Этот проект фокусируется на создании прототипа робота-манипулятора с управлением через контроллер-перчатку. Этот подход не только обеспечивает эффективное взаимодействие человека с роботом, но и решает проблемы эргономики и удобства управления.
Такой робот может быть применен в различных сферах, таких как медицина, строительство, промышленное производство, а также в ситуациях, где важны точность и чувствительность воздействия. Контроллер-перчатка делает управление роботом более естественным и интуитивным, уменьшая необходимость специализированного обучения пилотов устройства.
Проект также решает задачи, связанные с эргономикой и удобством управления. Это делает робота-манипулятора более доступным и простым в использовании, что может повысить эффективность в различных областях. Робот с контроллером-перчаткой особенно ценен в условиях, где требуется высокая точность и тонкость взаимодействия с объектами, в том числе в зонах, где человеку находиться даже короткий промежуток времени опасно.
Поэтому | разработка | технологически | передового
робота-манипулятора и инновационного метода управления, способствует улучшению взаимодействия человека с техникой в различных областях применения.

### 1.2 Цели и задачи

Цель работы: разработать полноценную модель робота манипулятора с управлением через специальный контроллер-перчатку.
Для успешного и эффективного выполнения цели проекта необходимо решить ряд следующих задач работы:
1. Проанализировать аналоги и готовые прототипы;

Провести исследование рынка и технологических решений для выявления существующих аналогов и прототипов, определить их преимущества и недостатки.
2. Составить функциональную схему продукта;
Определить | основные | функциональные | элементы | и
взаимосвязи между ними, создавая понятную схему для последующего проектирования.
3. Составить электрическую схему модели;
Разработать детальную электрическую схему, описывающую подключение и взаимодействие электронных компонентов робота.
4. Разработать трехмерную модель конструкции в программе 3D моделирования;
5. Подобрать необходимые компоненты и материалы;
6. Разработать печатные/макетные платы для размещения электроники;
Создать дизайн печатных плат, обеспечивающих эффективное размещение и взаимодействие электронных элементов.
7. Изготовить/Подготовить материалы для реализации модели робота;
8. Собрать конструкцию робота и объединить все компоненты; Выполнить сборку робота, установить компоненты согласно проектной документации, обеспечивая их взаимодействие.
9. Разработать программу для манипулятора и перчатки;
10. Запрограммировать перчатку и манипулятор;
11. Протестировать и модифицировать конструкцию и электронику робота;
12. Оценить и представить выполненную работу.

### 1.3 Анализ аналогов

В процессе исследования были рассмотрены аналоги и прототипы, представленные другими известными производителями роботов или командами энтузиастов. Подробная информация о сравнительных характеристиках этих манипуляторов приведена в таблице 1. В таблице представлена детализированная информация о ключевых особенностях и параметрах этих манипуляторов, призванных воплощать в себе передовые технологии и инженерное мастерство.

Таблица 1. Анализ аналогов роботов-манипуляторов, представленных на рынке.

Название | Визуальная картинка | Характеристики

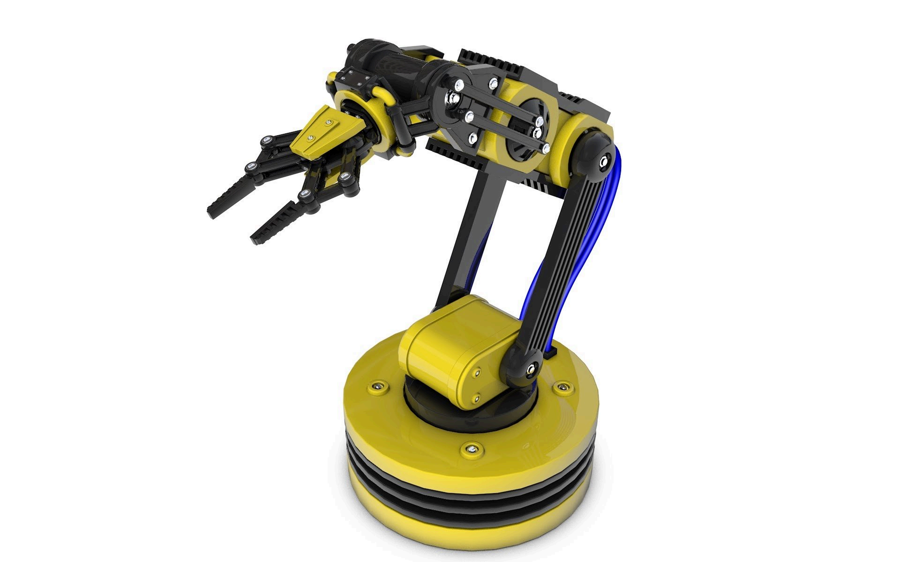
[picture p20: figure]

Робот-манипулятор LD-tg1400-6 | | Полезная нагрузка манипулятора достигает 6 кг. Рабочий радиус взаимодействия в районе 1000 мм Конструкция описана в виде Шарнирно-сочлененной структуре. Число степеней свободы - 4. Повторяемость: ±0.05 мм. Вес около 60 кг. Рабочая температура находиться в диапазоне -20°C~80°C

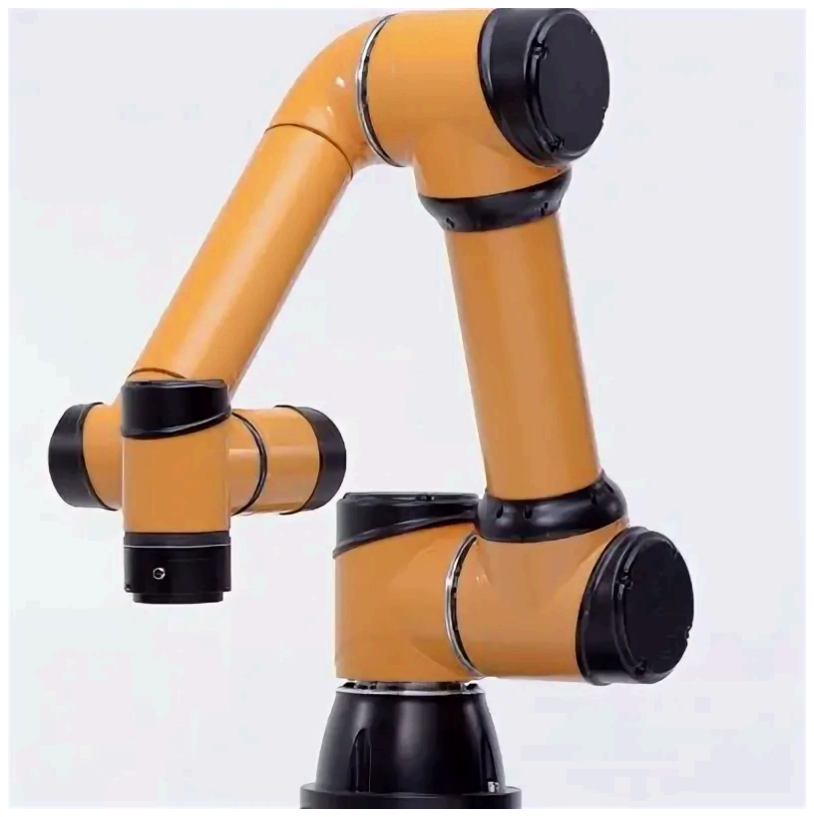
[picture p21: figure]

Манипулятор
AUBO i5

Манипулятор AUBO i5
предполагает полезную
нагрузку до 6 кг и рабочий радиус в 1000 мм. В его
конструкции присутствует 6 степеней свободы,
обеспечивая высокую
гибкость. Повторяемость в
пределах ±0.1 мм, вес
составляет примерно 40 кг. Способен эффективно
функционировать в широком
температурном диапазоне от 10°C до 50°C

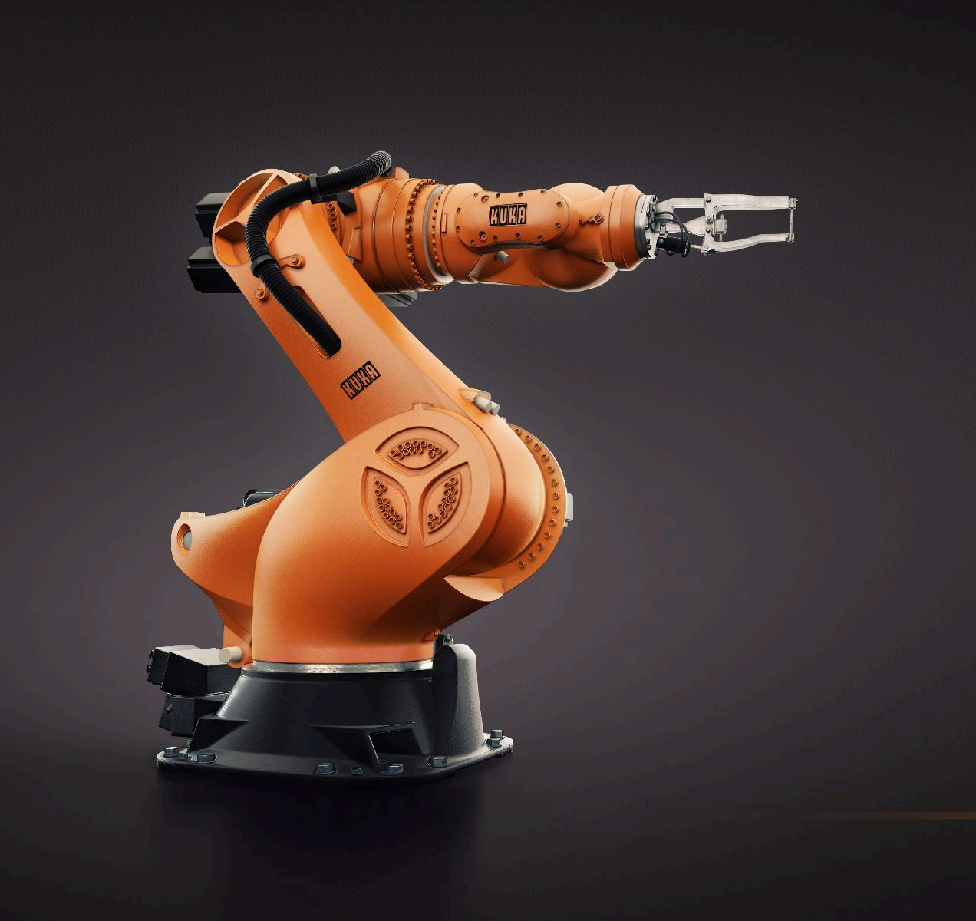
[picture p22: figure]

Робот-манипулятор
Kuka KR AGILUS

Полезная нагрузка: от 3 до 10 кг.
Рабочий радиус - от 600 до 1100 мм.
Основная структура робота: Шарнирно-сочлененная
конструкция с 6 степенями
свободы.
Повторяемость: высокая
точность с повторяемостью в пределах ±0.02 мм.
Вес в диапазоне 51-70 кг.
Рабочая температура:
стандартно в диапазоне от
10°C до 55°C.

Все эти манипуляторы имеют идентичную структурную особенность
- последовательную кинематику, однако их параметры значительно отличаются друг от друга.

### 1.4 Функциональная схема и формулировка

технического задания
Основной функциональной особенностью данного манипулятора является возможность управления им с использованием специальной перчатки, оборудованной сенсорами и датчиками. Эти устройства на перчатке реагируют на движения рук и пальцев пользователя, а затем транслируют эти данные в манипулятор для выполнения соответствующих задач. Для тех, кому вариант с управлением через перчатку не подходит, можно использовать другой контроллер, напоминающий обычный джойстик со стандартным управлением.
Перчатка обеспечивает точное и мгновенное распознавание жестов и движений, что позволяет оператору контролировать манипулятор с высокой степенью прецизионности. Такое управление особенно полезно в задачах, где требуется тонкая настройка и точность, например, в хирургии, производстве микроэлектроники или при работе с труднодоступными объектами.

Кроме того, система может быть дополнена силомоментной обратной связью, позволяющей пользователю чувствовать вес, форму и текстуру объектов, с которыми взаимодействует манипулятор. Это создает ощущение присутствия и повышает уровень контроля оператора.
Такой манипулятор с копирующим управлением представляет собой интегрированную и эргономичную систему, которая может быть применена в различных областях, требующих высокой точности и удобства управления.
В итоге было сформулировано следующее техническое задания:
1. Необходимо обеспечить стабильную связь между роботом манипулятором и контроллером удаленного управления. Перчатка или иной контроллер требуют постоянного питания, так как канал связи должен быть постоянно занят. Реализовать постоянную обратную связь между манипулятором и контроллером не сложно, однако хочется, чтобы при работе от аккумулятора перчатка или контроллер не разряжались в один момент, даже если данных не поступало.
2. Необходимо | реализовать | алгоритмы | | калибровки | шаговых
двигателей. Вся проблема в том, что при использовании шаговых двигателей в момент запуска, в большинстве случаев, они берут за свою стандартную позицию ту, с которой запустилась, а не ту, которую подразумевается. Для исправления этого недочета есть несколько способов решения, одним из них является способ калибровки манипулятора с помощью специальных алгоритмов.
3. Реализовать схему считывания данных от пользователя и перевод их на манипулятор. Для этого необходимо использовать модель радиосвязи NRF. Данные с перчатки передаются на манипулятор по специальному радиоканалу, настроенного вручную.
4. Реализовать модель перчатки. В перчатке должен присутствовать микроконтроллер на базе Arduino. Данные об отклонении руки на
заданном | промежутке | считываются | с | помощью | датчика
гироскопа-акселерометра mpu6050. В схеме должны присутствовать датчики магнитного поля или датчики холла. Закрепить датчики следует на 4-х пальцах перчатки, а на большом пальце той же перчатки необходимо разместить небольшой магнит.
5. Разработать алгоритм перевода угла наклона в скорость вращения определенного шагового двигателя. Для перевода угла наклона в скорость, вам необходимо учитывать изменение угла по времени. В физике и математике угловая скорость (или скорость вращения) обозначается символом ω (омега) и измеряется в радианах в секунду (рад/с).
6. Составить схему для манипулятора и реализовать ее в реальной жизни. Схема и 3Д модель должны соответствовать требованиям документации и правилам, описанным ГОСТ.
7. Разработать прошивку для перчатки и робота-манипулятора. Для реализации следует использовать микроконтроллер Arduino и среду программирования Arduino IDE. Необходимо, чтобы перчатка имела у себя 4 отдельных датчика холла на каждом пальце, за исключением большого пальца руки.
8. Протестировать систему в реальных условиях. Попробовать поднять предметы разной формы и веса в пределах допустимой нагрузки. В зависимости от проведенных тестов сделать техническую документацию, описывающие характеристики манипулятора.
9. Составить полную документацию к проекту.

### 2. КОНСТРУКТОРСКО-ТЕХНОЛОГИЧЕСКИЙ ЭТАП

### 2.1 Выбор технического оборудования

Для проектирования моделей использовался Autodesk Fusion 360. Он
является | мощным | программным | обеспечением | для
компьютерного-помощи-в-проектировании (САПР), предоставляющим ряд
преимуществ, | объясняющих | его | широкую | популярность.
Интегрированный подход Fusion 360 предоставляет интегрированную среду для 3D-моделирования, инженерного проектирования, симуляции, CAM (компьютерно-чертежное проектирование) и облачного хранения. Это позволяет пользователям работать над всеми аспектами проекта в одной среде, что способствует синхронизации данных и упрощает взаимодействие между различными этапами проектирования. Широкий функционал Fusion 360 включает в себя множество инструментов для создания 3D-моделей, выполнения анализа напряжений и тепловых карт, создания инструментальных траекторий для станков с ЧПУ и многое другое.

Для программирования основного микроконтроллера ATmega2560 было решено использовать среду Arduino IDE с оболочкой под ATmega2560 и язык программирования C++. Этот микроконтроллер является основой Arduino Mega, что обеспечивает широкие возможности для разработки и управления различными периферийными устройствами. Необходимый чип как раз используется платой Arduino Mega, именно она в проекте и была взята.

### 2.2 Конструкционные особенности

Для дальнейшей работы определим необходимые компоненты копирующего управления. Начнем непосредственную разработку с выполнения схемы перчатки. В качестве датчиков, управляющих движениями робота-манипулятора было принято решение использовать датчик гироскоп-акселерометра mpu6050. В зависимости от угла отклонения и вычислительного ускорения формируется понятие того, куда, как и с какой скоростью должен вращаться определенный двигатель. Для обеспечения взаимодействия пользователя и манипулятора, а также для интерпретации показаний датчиков использована плата Arduino Nano. Связь между элементами осуществляется по радиоканалу, который обеспечивают модули NRF24, установленные как на перчатку, так и на сам манипулятор. В качестве питающего элемента использован аккумулятор типа 18650 на 3.7 В. Данного аккумулятора хватит для использования перчатки в автономном режиме без дополнительных модулей усиления. Таким образом схема сборки электронных компонентов приведена на рисунке 1.

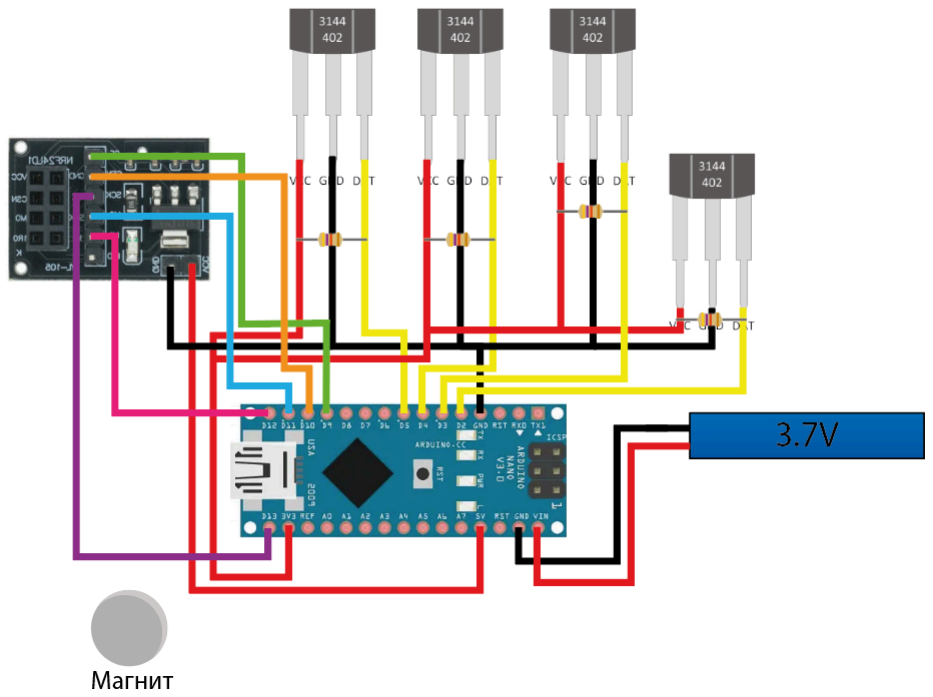
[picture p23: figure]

Рисунок 1. Схема сборки устройства, считывающего жесты, закрепленного на перчатке.

Далее перейдем к разработке манипулятора. Для первого прототипа будем использовать шаговые двигатели типа NEMA17. Такие двигатели широко распространены на рынке и обеспечивают необходимую точность перемещений робота, однако они имеют небольшой момент силы. Чтобы нивелировать этот недостаток, в манипуляторе применяются зубчатые передачи, установленные на звеньях. Модель манипулятора, построенного в программе Fusion 360 приведена на рисунке 2.

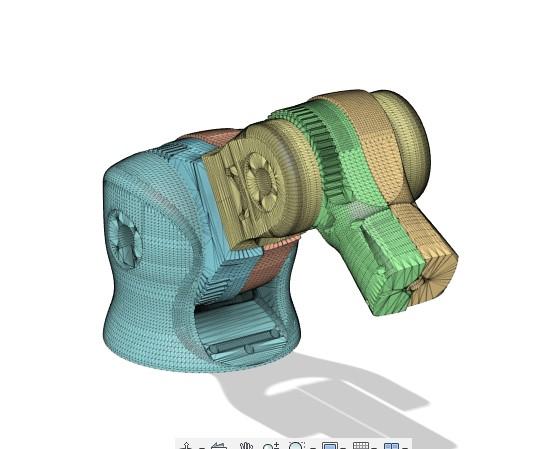
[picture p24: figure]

Рисунок 2. Манипулятор, построенный в программе Fusion 360.

Производство будет выполнено на 3D-принтере Flying Bear 5, что обеспечит необходимое качество производимых деталей. На рисунке отмечено цветами разделение частей деталей для производства. Далее
перейдем | к | формированию | электронной | схемы | компонентов
манипулятора.
Как было описано выше, для обеспечения перемещений роботом будут использованы двигатели типа NEMA17,которые будут подключены к плате Arduino с помощью драйвера A4988. Данный драйвер не требователен к управляющему сигналу, что делает его наиболее эффективным в этом проекте. Данные для перемещения Arduino будет получать с помощью радиомодуля NRF24. Сигнал можно усилить, поставив на место обычной NRF24 ту же модель, но с модулем усиления и антенной. Электросхема манипулятора приведена на рисунке 3.

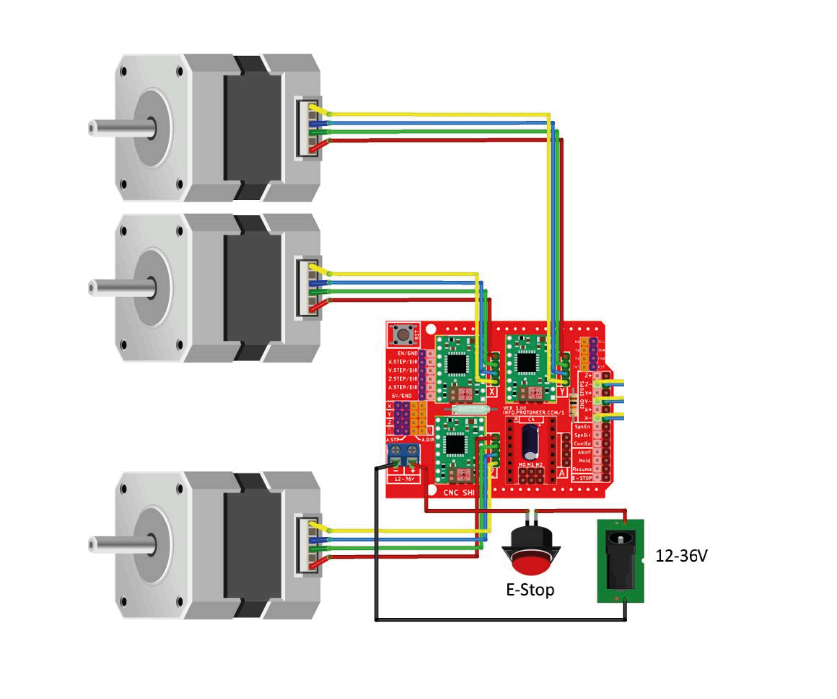
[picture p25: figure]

Рисунок 3. Электросхема управления манипулятором.

Таким образом схема управления манипулятором составлена. Теперь необходимо обеспечить сборку и взаимодействие оператора с манипулятором. Для этого составлена программа на языке Arduino, приведенная в приложении.

### 3. Написание программного кода проекта

### 3.1 Программный код перчатки

Программный код перчатки реализован на языке программирования C++. Используемые библиотеки находящиеся в открытом доступе. На рисунке 4 представлен фрагмент кода, на котором происходит момент инициализации перчатки, открытие радиоканала и инициализация самой mpu6050. Уникальный адрес для радиоканала задается вручную, что может

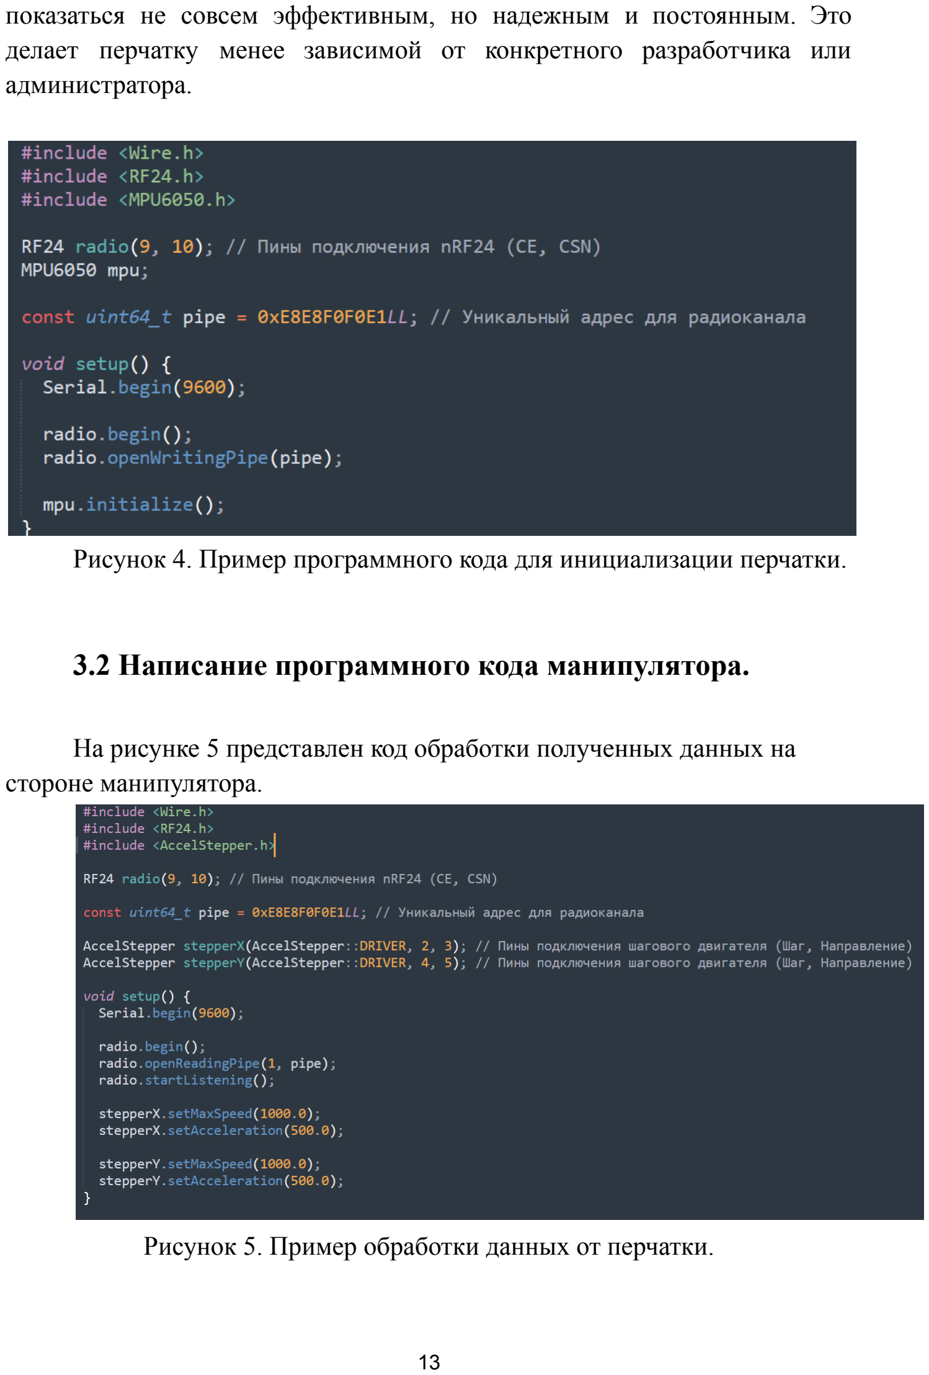
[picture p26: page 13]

показаться не совсем эффективным, но надежным и постоянным. Это делает перчатку менее зависимой от конкретного разработчика или администратора.

Рисунок 4. Пример программного кода для инициализации перчатки.

3.2 Написание программного кода манипулятора.

На рисунке 5 представлен код обработки полученных данных на стороне манипулятора.

Рисунок 5. Пример обработки данных от перчатки.

Важно понимать, что номера радиоканалов должны совпадать друг с другом, иначе соединения двух модулей между собой не произойдет.

### 4. Результаты

Цели и задачи данного проекта выполнены в полном объеме. Разработана вся необходимая документация, построены модели и электросхемы, детали переданы в производство, где успешно выполнены. Произведена дополнительная механическая обработка деталей из-за некоторых незначительных дефектов производства. Схемы собраны и
дополнительно | скорректированы | для | документации. | Написан
программный код, и обеспечивается устойчивое соединение между оператором и манипулятором. Проект проходит стадии финальной отладки и оптимизации.

### 5. Список используемой литературы

1. Банци М.« Arduino для начинающих волшебников» https://www.elec.ru/library/nauchnaya-i-tehnicheskaya-literatura/banci-arduino/ (https://www.elec.ru/library/nauchnaya-i-tehnicheskaya-literatura/banci-arduino/) Дата обращения: 25.12.2023;
2. Олег Миловзоров, Иван Панков - «Электроника. Базовый курс» https://krasnograd2008.ucoz.ru/load/uchebniki_dlja_vuzov/uchebniki_dlja_vuzov/oleg_milovzorov_ivan_pankov_ehlektronika_bazovyj_kurs/60-1-0-18 87 Дата обращения: 16.01.2024;
3. «Основы | 3д | моделирования | в | Компас | 3Д»
https://youtube.com/playlist?list=PLivkchQQojUVkmjov0UZrLz2X70HkV4gK&si=_3Ym10-ELJgqKk2p (https://youtube.com/playlist?list=PLivkchQQojUVkmjov0UZrLz2X70HkV4gK&si=_3Ym10-ELJgqKk2p) Дата обращения: 3.02.2024;

4. Пол Шерц и Симон Монк «Практическая электроника для изобретателей»
https://zametkioknigah.blogspot.com/2015/02/practical-electronics-for-in ventors.html (https://zametkioknigah.blogspot.com/2015/02/practical-electronics-for-inventors.html) Дата обращения: 8.01.2024;

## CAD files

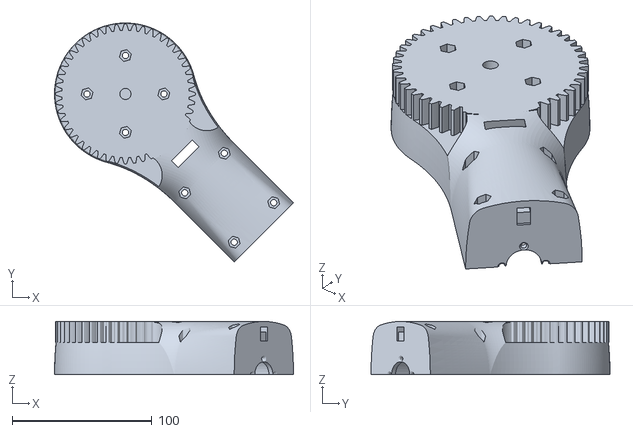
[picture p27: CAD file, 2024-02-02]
files/STL/part_B.stl
171.0 x 171.0 x 38.0

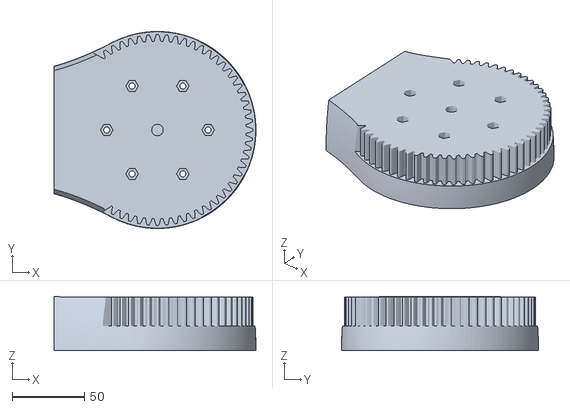
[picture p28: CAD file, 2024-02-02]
files/STL/arm1_B.stl
139.4 x 136.0 x 37.4

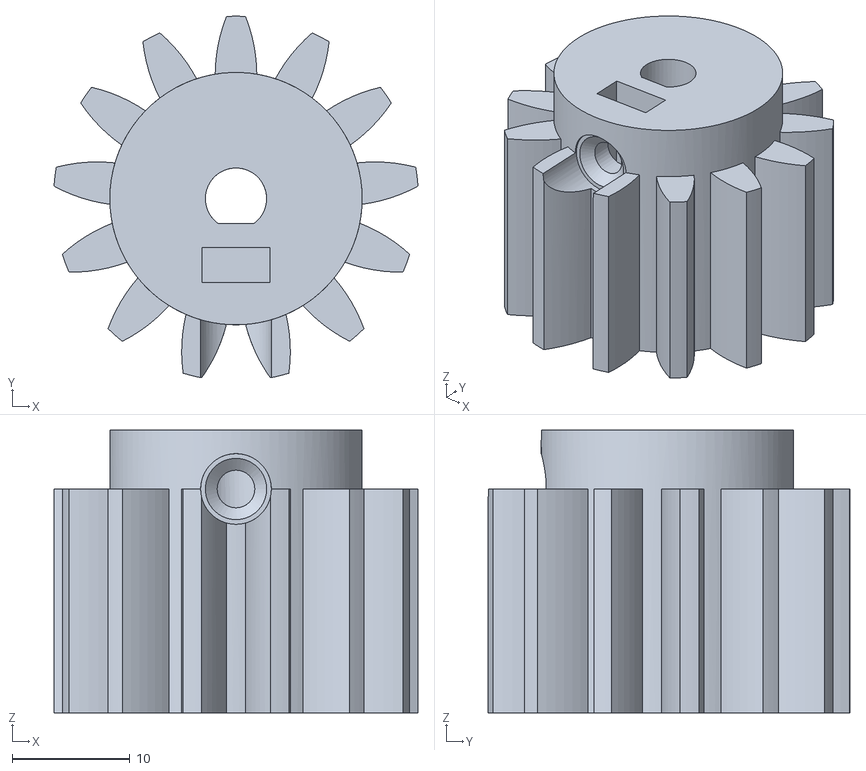
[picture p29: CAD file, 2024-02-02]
files/STL/gear_a.stl
30.9 x 30.7 x 24.0

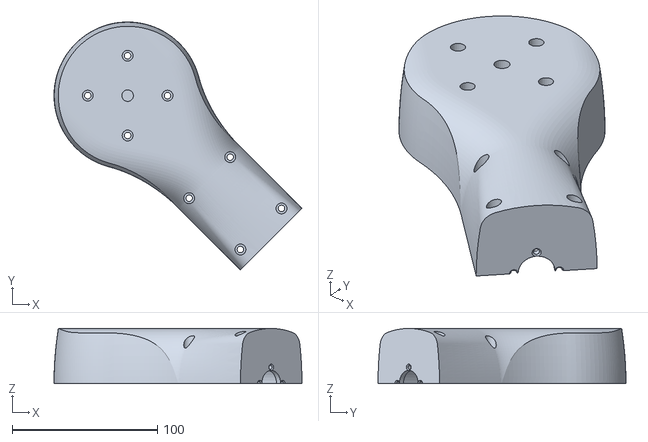
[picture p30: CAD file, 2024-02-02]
files/STL/part_A.stl
171.0 x 171.0 x 38.0

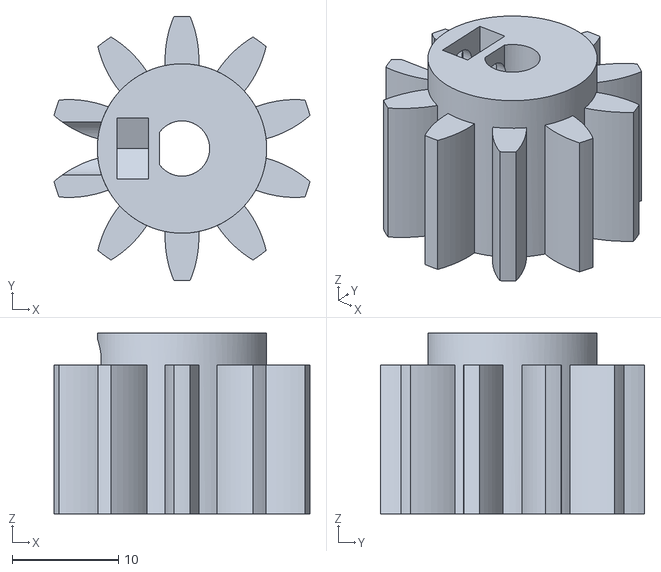
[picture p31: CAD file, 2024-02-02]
files/STL/gear_b.stl
24.0 x 24.8 x 17.0

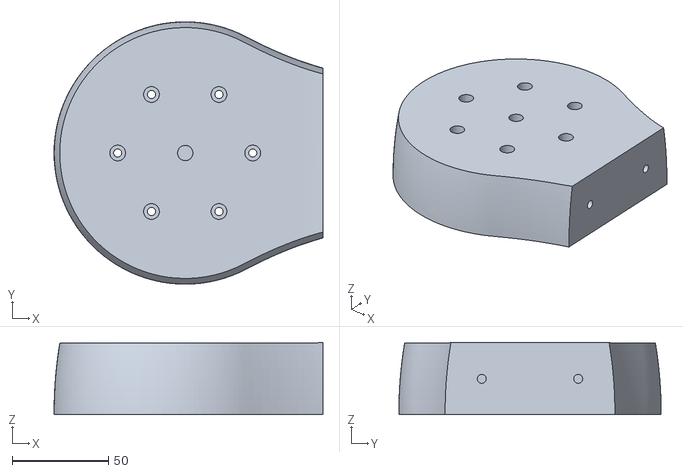
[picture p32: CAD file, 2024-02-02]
files/STL/arm1_A.stl
139.4 x 136.0 x 37.4

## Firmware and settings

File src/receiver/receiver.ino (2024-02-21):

#include <FastLED.h>


#define DATA_PIN A0
#define LED_TYPE WS2812B
#define COLOR_ORDER GRB
#define NUM_LEDS 72

CRGB leds[NUM_LEDS];

void setup() {
  FastLED.addLeds<LED_TYPE, DATA_PIN, COLOR_ORDER>(leds, NUM_LEDS).setCorrection(TypicalLEDStrip);
  FastLED.setBrightness(100);
  Serial.begin(9600);
}

void loop() {
  // Вращение светодиодами синего цвета
  for (int cnt=0; cnt < 5; cnt++){
    for (int i = 1; i < NUM_LEDS - 2; i++) {
      fill_solid(leds, NUM_LEDS, CRGB::White);
      leds[i-1] = CRGB::BLUE;  // Оставим один светодиод белым для визуализации вращения
      leds[i] = CRGB::White;
      leds[i+1] = CRGB::White;
      FastLED.show();
      delay(50);
      FastLED.clear();
    }
  }

  // Мигание зеленым цветом три раза
  for (int j = 0; j < 5; j++) {
    fill_solid(leds, NUM_LEDS, CRGB::Red);
    FastLED.show();
    delay(500);
    FastLED.clear();
    FastLED.show();
    delay(500);
    FastLED.clear();
  }

  // Горение красным цветом
  // fill_solid(leds, NUM_LEDS, CRGB::Green);
  // FastLED.show();
  fill_solid(leds, NUM_LEDS, CRGB::Red);
  delay(10000);
}

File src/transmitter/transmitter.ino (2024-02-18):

#include <SPI.h>
#include <RF24.h>

// Указываем пины для подключения модуля nRF24L01
const int cePin = 9;
const int csPin = 10;

// Создаем объект RF24 для работы с модулем
RF24 radio(cePin, csPin);

void setup() {
  Serial.begin(9600);

  // Инициализируем модуль nRF24L01
  radio.begin();

  // Открываем канал для приема данных (должен совпадать с каналом на передающей стороне)
  radio.openReadingPipe(1, 0xF0F0F0F0E1LL);  // Уникальный адрес для приема данных

  // Включаем приемник
  radio.startListening();
}

void loop() {
  Serial.print(".");
  // Проверяем наличие данных для приема
  if (radio.available()) {
    char message[32] = {0};  // Буфер для принятого сообщения
    radio.read(&message, sizeof(message));

    Serial.print("Принято сообщение: ");
    Serial.println(message);
  }
}

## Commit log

2024-01-10 add main script to arduino hand
2024-02-02 add models
    [Am_part_2.stl, Am_part_2_gear.stl, ArmPrint_A_1.stl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]
2024-02-18 new data
    [arm1_A.stl, arm1_B.stl, gear_a.stl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]
